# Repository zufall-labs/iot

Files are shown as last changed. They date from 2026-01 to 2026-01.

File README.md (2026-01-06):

# IoT

🤖 Everything IoT in regards to Zufall Labs hardware products

# IoT Entropy-as-a-Service

Hardware and software for generating and distributing true random numbers from chaotic oscillators.

## Architecture

- **Hardware**: Chaos Circuits Board with 4 oscillators + Raspberry Pi 4 + ADC
- **Firmware**: N/A (using Raspberry Pi OS)
- **Software**: Python-based entropy generation and MQTT publishing
- **Backend**: Service mesh for distribution (separate repos)

## Quick Start

### Hardware Setup

1. Connect Waveshare AD HAT to Raspberry Pi
2. Connect chaos circuit VCE1 → ADC IN3
3. Power: Pi 5V → Board VIN5V

### Software Setup
```bash
cd software/adapters/adc-adapters/waveshare-ads1263
pip install numpy scipy paho-mqtt

# Run diagnostics
cd ../../tools/diagnostics
sudo python3 chaos_diagnostic.py
```

## Repository Structure
```
/
├── .github/                      # GitHub specific configurations
│   ├── workflows/                # GitHub Actions CI/CD pipelines
│   ├── ISSUE_TEMPLATE/          # Issue templates
│   └── PULL_REQUEST_TEMPLATE/   # PR templates
│
├── hardware/                     # All hardware-related files
│   ├── mechanical/              # 3D designs and mechanical components
│   │   ├── cad/                 # CAD files (Fusion 360, SolidWorks, etc.)
│   │   ├── stl/                 # 3D printable files
│   │   └── drawings/            # Technical drawings and dimensions
│   │
│   ├── electronics/             # Electronic design files
│   │   ├── kicad/              # KiCad project files
│   │   │   ├── lib/            # Custom component libraries
│   │   │   ├── fp-lib-table    # Footprint library configurations
│   │   │   └── sym-lib-table   # Symbol library configurations
│   │   ├── datasheets/         # Component datasheets
│   │   └── production/         # Gerber files, BOM, assembly instructions
│   │
│   └── interfaces/             # Hardware interface specifications
│       ├── connectors/         # Connector pinouts and specifications
│       └── protocols/          # Communication protocol specifications
│
├── firmware/                    # Device firmware
│   ├── bootloader/             # Bootloader source code
│   ├── main/                   # Main firmware source code
│   ├── libs/                   # Shared firmware libraries
│   └── tools/                  # Firmware-specific tools
│
├── software/                   # Software components
│   ├── core/                   # Core business logic
│   ├── adapters/              # Hardware abstraction layers
│   │   ├── sensor-adapters/   # Different sensor implementations
│   │   └── comm-adapters/     # Communication protocol adapters
│   ├── api/                   # API definitions and implementations
│   ├── web/                   # Web applications
│   ├── mobile/                # Mobile applications
│   └── tools/                 # Development and debugging tools
│
├── tests/                      # Test suites
│   ├── hardware/              # Hardware test specifications
│   ├── firmware/              # Firmware test suites
│   └── software/              # Software test suites
│
├── docs/                       # Documentation
│   ├── architecture/          # System architecture documents
│   ├── hardware/              # Hardware documentation
│   ├── firmware/              # Firmware documentation
│   ├── software/              # Software documentation
│   ├── api/                   # API documentation
│   └── user/                  # End-user documentation
│
├── tools/                      # Development and build tools
│   ├── build-scripts/         # Build automation scripts
│   ├── ci-scripts/            # CI/CD helper scripts
│   └── dev-tools/             # Development utilities
│
├── config/                     # Configuration files
│   ├── dev/                   # Development environment configs
│   ├── prod/                  # Production environment configs
│   └── test/                  # Test environment configs
│
├── .gitignore                 # Git ignore rules
├── .editorconfig              # Editor configuration
├── LICENSE                    # Project license
├── README.md                  # Project overview and setup instructions
└── CONTRIBUTING.md            # Contribution guidelines
```

## Current Status

✅ Hardware: Chaos Circuits Board designed and tested
✅ Software: Chaos diagnostic tool working (Score: 90+)
🚧 Next: MQTT integration for entropy publishing

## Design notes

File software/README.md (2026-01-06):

# IoT Software Components

## Structure

- **adapters/**: Hardware abstraction layers
  - `adc-adapters/waveshare-ads1263/`: Driver for Waveshare High-Precision AD HAT
  
- **core/**: Core business logic
  - `entropy-generator/`: Chaos-based entropy generation
  - `mqtt-publisher/`: MQTT publishing logic
  
- **tools/**: Development and debugging tools
  - `diagnostics/`: Chaos diagnostic tool

## Setup
```bash
pip install numpy scipy paho-mqtt
```

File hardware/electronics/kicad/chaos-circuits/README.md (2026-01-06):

# Chaos Circuits Board

4 chaotic oscillator circuits on one board:
1. Chua's Circuit
2. Lorenz Attractor
3. Rössler Attractor  
4. Two-Transistor RC Oscillator

## Files

- `Chaos Circuits.kicad_pcb`: PCB layout
- `Chaos Circuits.kicad_sch`: Schematic
- `Chaos Circuits.kicad_pro`: KiCad project

## Production Files

See `/hardware/electronics/production/chaos-circuits/`

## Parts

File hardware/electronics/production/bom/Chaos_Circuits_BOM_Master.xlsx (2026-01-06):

Item # | *Designator | *Qty | Manufacturer | *Mfg Part # | Description / Value | *Package/Footprint | Type | Your Instructions / Notes
1 | C1,C2,C3,C4,C5 | 5 | Murata | GCM31CD71H106KE36K | 10 µF ±10% 50V Ceramic Capacitor X7T 1206 (3216 Metric) | 1206 | SMT
2 | C6,C12,C13,C18 | 4 | Kemet | C0805C104J5RAC7800 | 0.1 µF ±5% 50V Ceramic Capacitor X7R 0805 (2012 Metric) | 0805 | SMT
3 | C7 | 1 | Kemet | C0805C103F5GAC7800 | 10000 pF ±1% 50V Ceramic Capacitor C0G, NP0 0805 (2012 Metric) | 0805 | SMT
4 | C8,C9,C10,C11,C14,C15,C16,C17,C19,C20,C21,C22,C23,C24,C30,C31,C33,C34,C35,C36,C37,C38,C39,C40,C41,C42,C44,C45,C46,C47,C48,C49 | 32 | Samsung Electro-Mechanics | CL21B105KBFNNNE | 1 µF ±10% 50V Ceramic Capacitor X7R 0805 (2012 Metric) | 0805 | SMT
5 | C25,C26,C27 | 3 | KEMET | C0805C102J5GAC7800 | 1000 pF ±5% 50V Ceramic Capacitor C0G, NP0 0805 (2012 Metric) | 0805 | SMT
6 | C28 | 1 | YAGEO | CC0805JRNPO9BN361 | 360 pF ±5% 50V Ceramic Capacitor C0G, NP0 0805 (2012 Metric) | 0805 | SMT
7 | C29,C32,C43 | 3 | Samsung Electro-Mechanics | CL21B222JBANNNC | 2200 pF ±5% 50V Ceramic Capacitor X7R 0805 (2012 Metric) | 0805 | SMT
8 | D1,D2 | 2 | Littelfuse Inc. | SMBJ18CA | 24.4V Clamp 24.6A Ipp Tvs Diode Surface Mount DO-214AA (SMBJ) | SMB | SMT
9 | D3,D4 | 2 | STMicroelectronics | STPS2H100A | Diode 100 V 2A Surface Mount SMA (DO-214AC) | SMA | SMT
10 | D5,D6,D8 | 3 | Kingbright | APT3216LZGCK | Green 525nm LED Indication - Discrete 2.65V 1206 | 1206 | SMT
11 | J1 | 1 | Phoenix Contact | 1729131 | PCB terminal block, nominal current: 13.5 A, rated voltage (III/2): 400 V, | Connector | TH
12 | J2 | 1 | TE Connectivity AMP Connectors | 796681-2 | 2 Position Wire to Board Terminal Block Horizontal with Board 0.197" (5.00mm) Through Hole | Connector | TH
13 | L1 | 1 | Bourns Inc. | RL181S-183J-RC | 18 mH Shielded Drum Core, Wirewound Inductor 21 mA 17Ohm Max Radial, Vertical Cylinder | Radial, Vertical Cylinder | TH
14 | Q1,Q2 | 2 | onsemi | BC547CTA | Bipolar (BJT) Transistor NPN 45 V 100 mA 300MHz 500 mW Through Hole TO-92-3 | TO-92-3 | TH
15 | R1,R2,R3 | 3 | YAGEO | RC0603FR-074K7L | RES 4.7K OHM 1% 1/10W 0603 | 0603 | SMT
16 | R4 | 1 | Bourns Inc. | 3310Y-001-202L | 2k Ohm 1 Gang Linear Panel Mount Potentiometer None 1.0 Kierros Conductive Plastic 0.25W, 1/4W PC Pins | Pot | TH
17 | R5 | 1 | Stackpole Electronics Inc | RMCF1206ZT0R00 | RES 0 OHM JUMPER 1/4W 1206 | 1206 | SMT
18 | R7,R11 | 2 | Vishay Dale | CRCW080522K0FKEAC | RES 22K OHM 1% 1/8W 0805 | 0805 | SMT
19 | R8 | 1 | Vishay Dale | CRCW08053K30FKEAC | RES 3.3K OHM 1% 1/8W 0805 | 0805 | SMT
20 | R9 | 1 | TE Connectivity Passive Product | CRG0805F2K2 | RES SMD 2.2K OHM 1% 1/8W 0805 | 0805 | SMT
21 | R10,R13 | 2 | TE Connectivity Passive Product | CRG0805F220R | RES SMD 220 OHM 1% 1/8W 0805 | 0805 | SMT
22 | R12,R19,R28,R29,R32 | 5 | Panasonic Electronic Components | ERA-6AEB104V | RES SMD 100K OHM 0.1% 1/8W 0805 | 0805 | SMT
23 | R14 | 1 | Panasonic Electronic Components | ERA-6AEB3572V | RES SMD 35.7K OHM 0.1% 1/8W 0805 | 0805 | SMT
24 | R15,R17,R22,R23,R30,R31,R34,R35,R36,R38,R42,R43,R44,R45,R46 | 15 | Susumu | RG2012P-103-B-T5 | RES SMD 10K OHM 0.1% 1/8W 0805 | 0805 | SMT
25 | R16 | 1 | YAGEO | RT0805BRD071ML | RES SMD 1M OHM 0.1% 1/8W 0805 | 0805 | SMT
26 | R18 | 1 | YAGEO | YAGEO | RES SMD 374K OHM 0.1% 1/8W 0805 | 0805 | SMT
27 | R20,R21,R39 | 3 | YAGEO | RC0805FR-075K1L | RES 5.1K OHM 1% 1/8W 0805 | 0805 | SMT
28 | R24 | 1 | TE Connectivity Passive Product | CRG0805F30K | RES SMD 30K OHM 1% 1/8W 0805 | 0805 | SMT
29 | R25,R41 | 2 | Bourns Inc. | 3310Y-001-104L | 100k Ohm 1 Gang Linear Panel Mount Potentiometer None 1.0 Kierros Conductive Plastic 0.25W, 1/4W PC Pins | Pot | TH
30 | R27 | 1 | TE Connectivity Passive Product | CRG0805F15K | RES SMD 15K OHM 1% 1/8W 0805 | 0805 | SMT
31 | R33 | 1 | YAGEO | RC0805FR-07560KL | RES SMD 100K OHM 0.1% 1/8W 0805 | 0805 | SMT
32 | R37 | 1 | YAGEO | RC0805FR-0756KL | RES 56K OHM 1% 1/8W 0805 | 0805 | SMT
33 | R40 | 1 | Panasonic Electronic Components | ERJ-6ENF3903V | RES SMD 390K OHM 1% 1/8W 0805 | 0805 | SMT
34 | R47,R48,R49,R50 | 4 | YAGEO | RC0805FR-07470RL | RES 470 OHM 1% 1/8W 0805 | 0805 | SMT
35 | U1,U2,U3,U4,U5,U8,U9,U10,U11,U12,U14,U15,U16 | 13 | Texas Instruments | TL081HIDR | J-FET Amplifier 1 Circuit Push-Pull 8-SOIC | 8-SOIC | SMT
36 | U6,U7,U13 | 3 | Analog Devices Inc. | AD633JRZ-R7 | Analog Multiplier 4-Quadrant 8-SOIC | 8-SOIC | SMT

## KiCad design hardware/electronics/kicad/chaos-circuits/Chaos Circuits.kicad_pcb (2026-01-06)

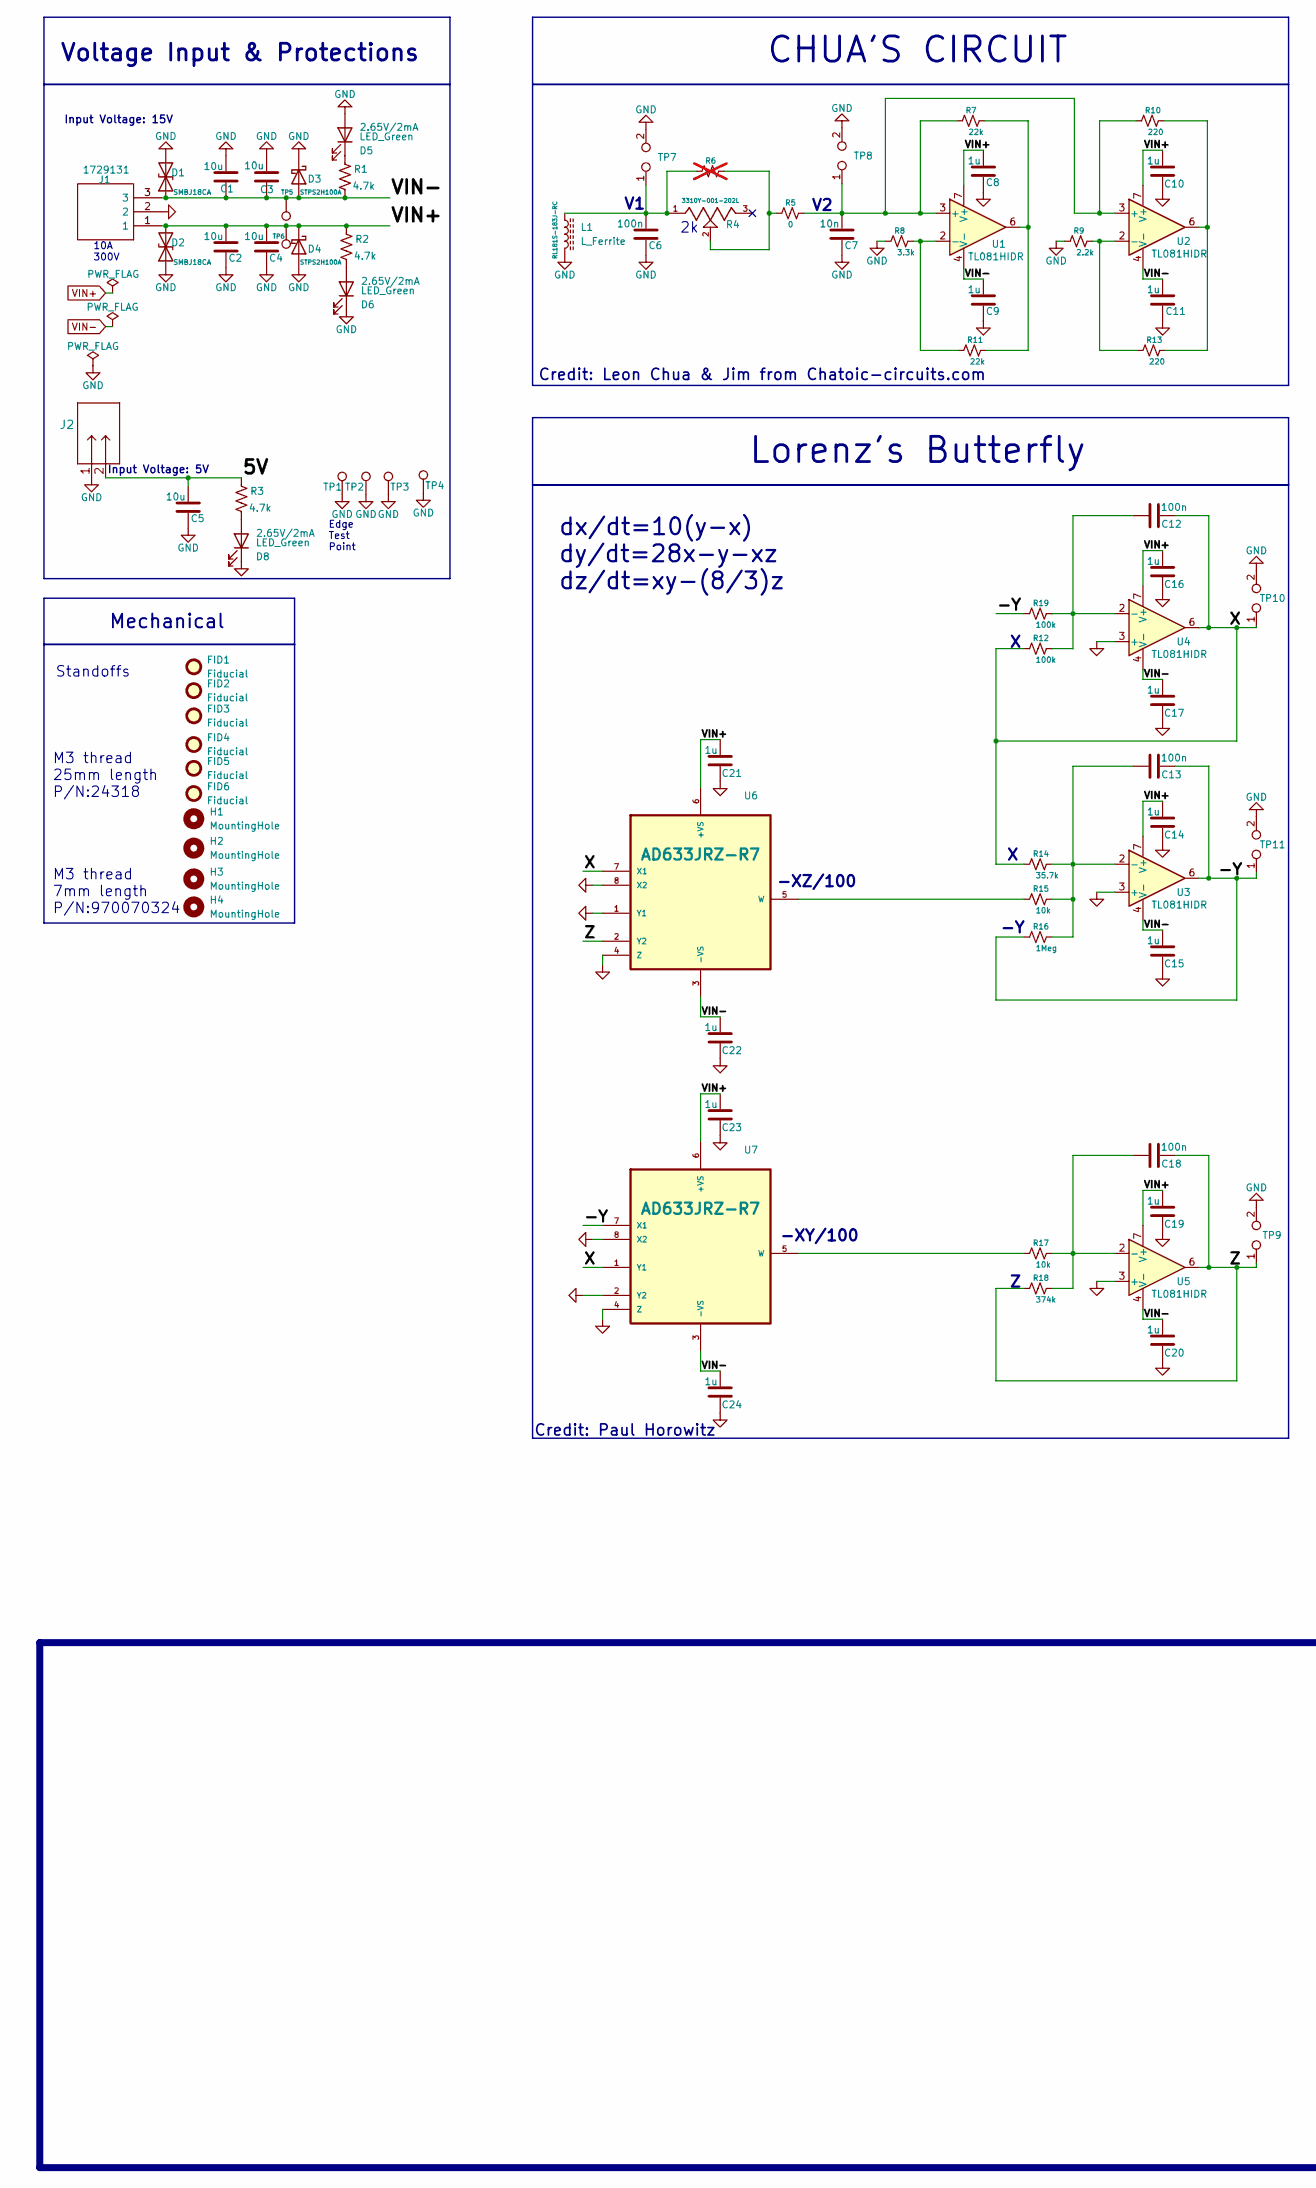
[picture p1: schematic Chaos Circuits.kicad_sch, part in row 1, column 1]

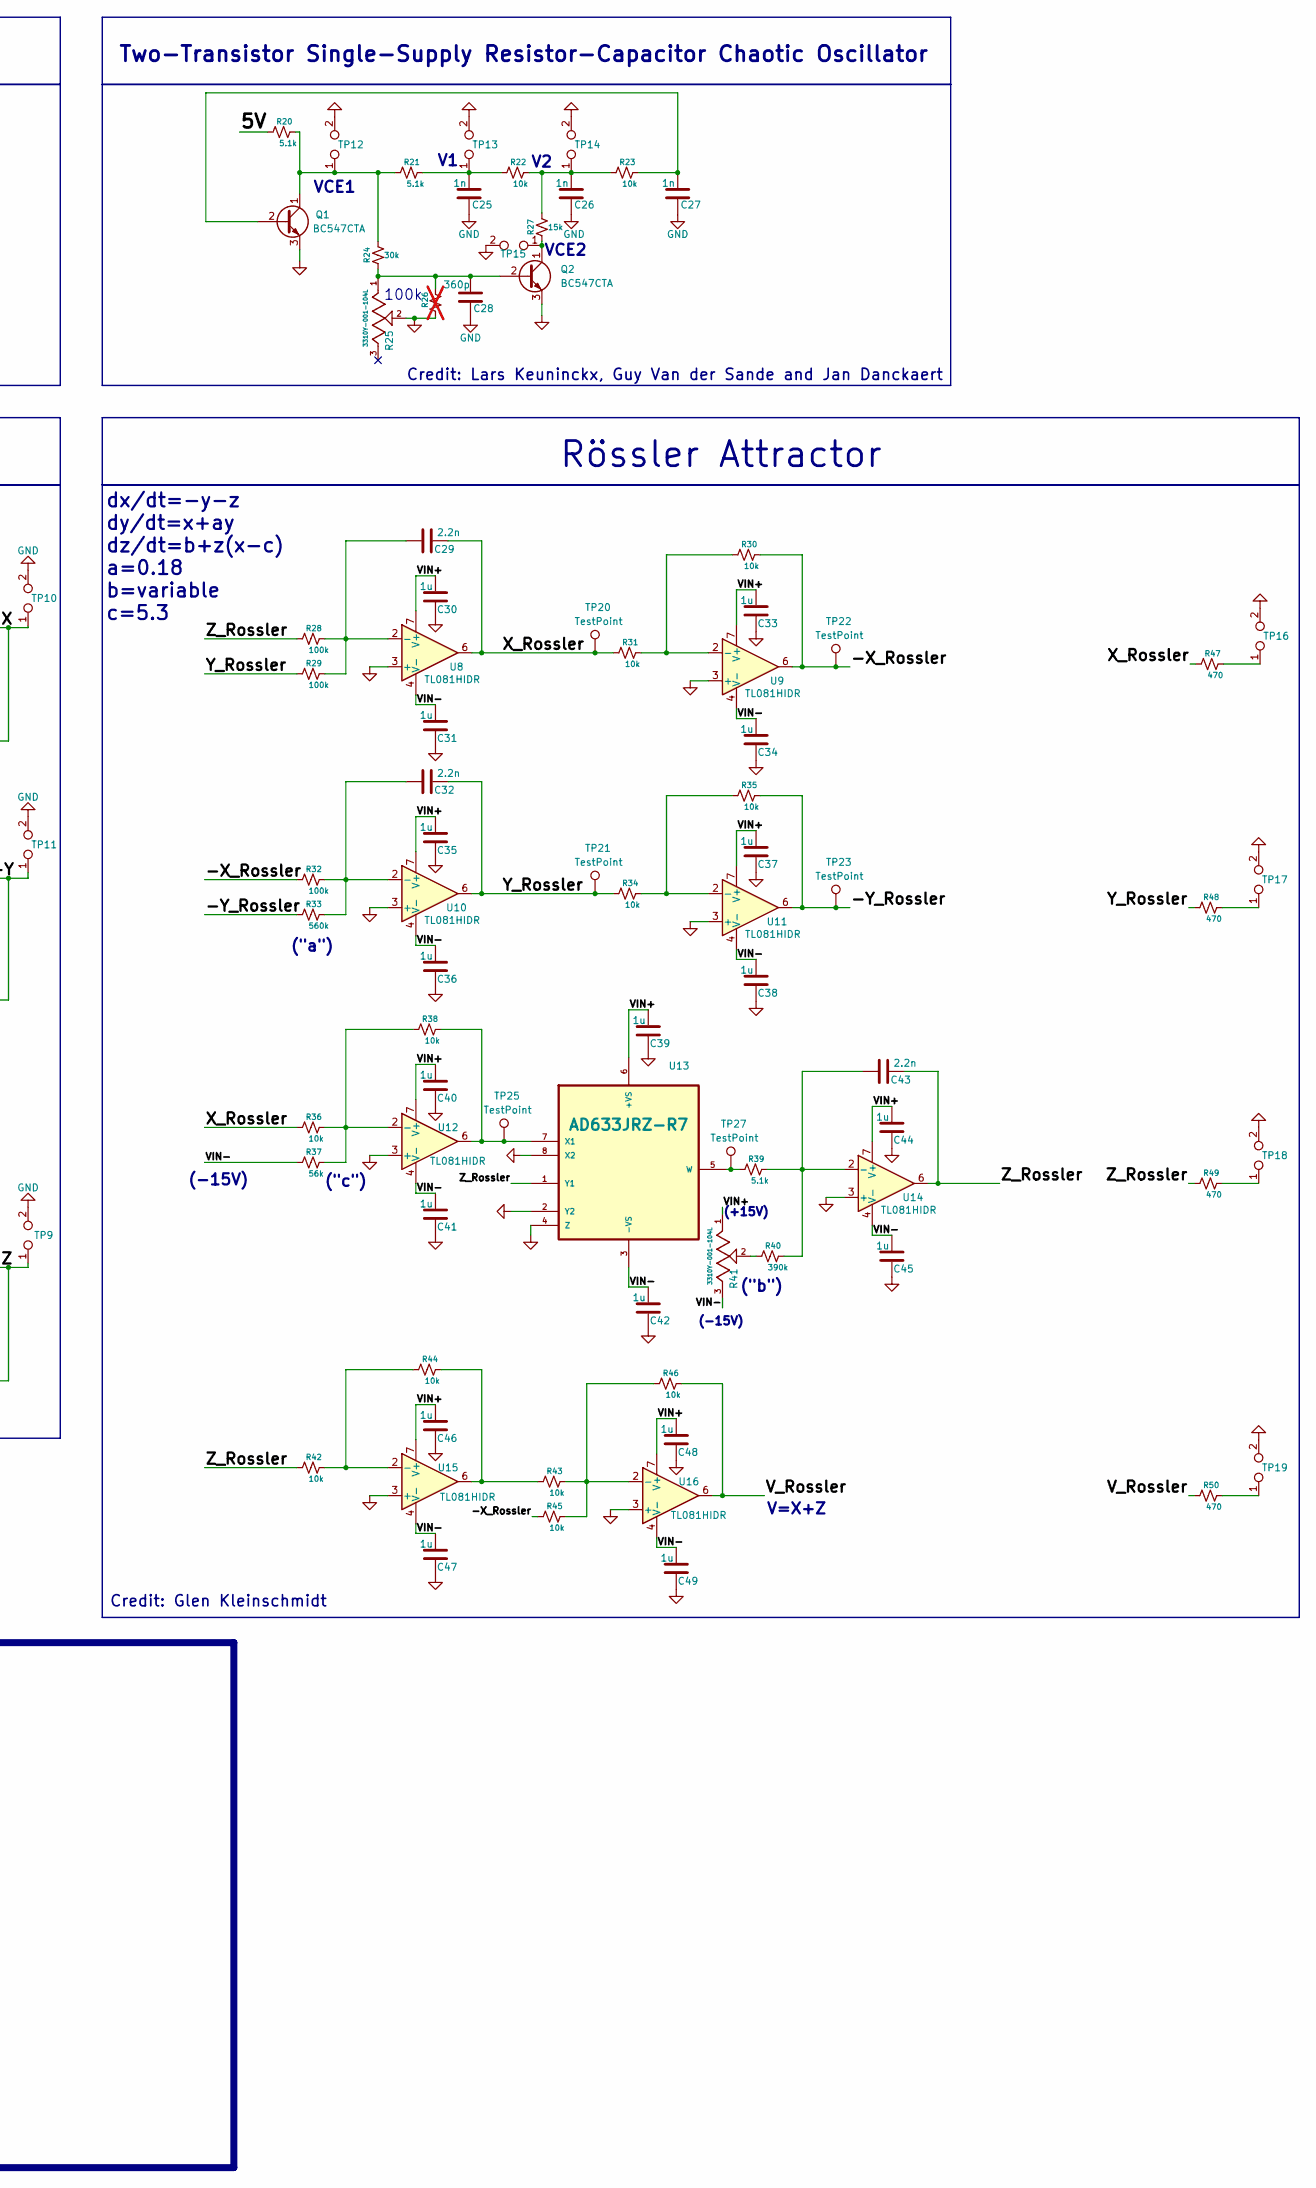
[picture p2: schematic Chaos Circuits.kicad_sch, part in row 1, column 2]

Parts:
C1, C2, C3, C4, C5: 10u; C_1206_3216Metric; Tolerance 10%; Voltage Rating 50V; Part Number GCM31CD71H106KE36K
C6, C12, C13, C18: 100n; C_0805_2012Metric; Tolerance 5%; Voltage Rating 50V; Part Number C0805C104J5RAC7800
C7: 10n; C_0805_2012Metric; Tolerance 1%; Voltage Rating 50V; Part Number C0805C103F5GAC7800
C8, C9, C10, C11, C14, C15, C16, C17, C19, C20, C21, C22, C23, C24, C30, C31, C33, C34, C35, C36, C37, C38, C39, C40, C41, C42, C44, C45, C46, C47, C48, C49: 1u; C_0805_2012Metric; Tolerance 10%; Voltage Rating 50V; Part Number CL21B105KBFNNNE
C25, C26, C27: 1n; C_0805_2012Metric; Tolerance 5%; Voltage Rating 50V; Part Number C0805C102J5GAC7800
C28: 360p; C_0805_2012Metric; Tolerance 5%; Voltage Rating 50V; Part Number CC0805JRNPO9BN361
C29, C32, C43: 2.2n; C_0805_2012Metric; Tolerance 5%; Voltage Rating 50V; Part Number CL21B222JBANNNC
D1, D2: SMBJ18CA; D_SMB; Part Number SMBJ18CA
D3, D4: STPS2H100A; SMA_STM; Voltage Rating 100V 2A; Part Number STPS2H100A
D5, D6, D8: LED_Green; LED_1206_3216Metric_Pad1.42x1.75mm_HandSolder; Voltage Rating 2.65V/2mA; Part Number APT3216LZGCK
FID1, FID2, FID3, FID4, FID5, FID6: Fiducial; Fiducial_1mm_Mask2mm
H1, H2, H3, H4: MountingHole; MountingHole_3.5mm_Pad_TopBottom
J1: 1729131; Manufacturer_Part_Number 1729131; Mouser Part Number 651-1729131
J2: 796681-2; 796681-2_TEC; Part Number 796681-2
L1: L_Ferrite; L_Radial_D10.5mm_P5.00mm_Abacron_AISR-01; Power Rating 21mA; Part Number RL181S-183J-RC
Q1, Q2: BC547CTA; TO-92_Inline; Part Number BC547CTA
R1, R2, R3: 4.7k; R_0603_1608Metric; Power Rating 0.1W; Tolerance 1%; Part Number RC0603FR-074K7L
R4: 3310Y-001-202L; TRIM_3310Y-001-202L; Power Rating 0.25W; Part Number 3310Y-001-202L
R5: 0; R_1206_3216Metric; Power Rating 1/4W; Part Number RMCF1206ZT0R00
R6, R26: 0; R_1206_3216Metric; Power Rating 1/4W; Part Number RMCF1206ZT0R00; not fitted
R7, R11: 22k; R_0805_2012Metric; Power Rating 1/8W; Tolerance 1%; Part Number CRCW080522K0FKEAC
R8: 3.3k; R_0805_2012Metric; Power Rating 1/8W; Tolerance 1%; Part Number CRCW08053K30FKEAC
R9: 2.2k; R_0805_2012Metric; Power Rating 1/8W; Tolerance 1%; Part Number CRG0805F2K2
R10, R13: 220; R_0805_2012Metric; Power Rating 1/8W; Tolerance 1%; Part Number CRG0805F220R
R12, R19, R28, R29, R32: 100k; R_0805_2012Metric; Power Rating 1/8W; Tolerance 0.1%; Part Number ERA-6AEB104V
R14: 35.7k; R_0805_2012Metric; Power Rating 1/8W; Tolerance 0.1%; Part Number ERA-6AEB3572V
R15, R17, R22, R23, R30, R31, R34, R35, R36, R38, R42, R43, R44, R45, R46: 10k; R_0805_2012Metric; Power Rating 1/8W; Tolerance 0.1%; Part Number RG2012P-103-B-T5
R16: 1Meg; R_0805_2012Metric; Power Rating 1/8W; Tolerance 0.1%; Part Number RT0805BRD071ML
R18: 374k; R_0805_2012Metric; Power Rating 1/8W; Tolerance 0.1%; Part Number YAGEO
R20, R21, R39: 5.1k; R_0805_2012Metric; Power Rating 1/8W; Tolerance 1%; Part Number RC0805FR-075K1L
R24: 30k; R_0805_2012Metric; Power Rating 1/8W; Tolerance 1%; Part Number CRG0805F30K
R25, R41: 3310Y-001-104L; TRIM_3310Y-001-202L; Power Rating 0.25W; Part Number 3310Y-001-104L
R27: 15k; R_0805_2012Metric; Power Rating 1/8W; Tolerance 1%; Part Number CRG0805F15K
R33: 560k; R_0805_2012Metric; Power Rating 1/8W; Tolerance 1%; Part Number RC0805FR-07560KL
R37: 56k; R_0805_2012Metric; Power Rating 1/8W; Tolerance 1%; Part Number RC0805FR-0756KL
R40: 390k; R_0805_2012Metric; Power Rating 1/8W; Tolerance 1%; Part Number ERJ-6ENF3903V
R47, R48, R49, R50: 470; R_0805_2012Metric; Power Rating 1/8W; Tolerance 1%; Part Number RC0805FR-07470RL
TP1: TestPoint; TestPoint_THTPad_D3.0mm_Drill1.5mm
TP2, TP3, TP4, TP5, TP6: TestPoint; TestPoint_THTPad_D2.0mm_Drill1.0mm
TP7, TP8, TP9, TP10, TP11, TP12, TP13, TP14, TP15, TP16, TP17, TP18, TP19: TestPoint_2Pole; TestPoint_Bridge_Pitch7.62mm_Drill1.3mm
TP20, TP21, TP22, TP23, TP25, TP27: TestPoint; TestPoint_Keystone_5005-5009_Compact; Part Number 5005
U1, U2, U3, U4, U5, U8, U9, U10, U11, U12, U14, U15, U16: TL081HIDR; SOIC8_D_TEX; Part Number TL081HIDR
U6, U7, U13: AD633JRZ-R7; AD633; Part Number AD633JRZ-R7

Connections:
/5V: C5.1, J2.2, R3.1, R20.1
/-X_Rossler: R30.2, R32.1, R45.1, TP22.1, U9.6
/-Y: C13.2, R16.1, R19.1, TP11.1, U3.6, U7.7 (X1)
/-Y_Rossler: R33.1, R35.2, TP23.1, U11.6
/V_Rossler: R46.2, R50.1, U16.6
/X: C12.2, R12.1, R14.1, TP10.1, U4.6, U6.7 (X1), U7.1 (Y1)
/X_Rossler: C29.2, R31.1, R36.1, R47.1, TP20.1, U8.6
/Y_Rossler: C32.2, R29.1, R34.1, R48.1, TP21.1, U10.6
/Z: C18.2, R18.1, TP9.1, U5.6, U6.2 (Y2)
/Z_Rossler: C43.2, R28.1, R42.1, R49.1, U13.1 (Y1), U14.6
GND: C1.1, C2.2, C3.1, C4.2, C5.2, C6.2, C7.2, C8.2, C9.2, C10.2, C11.2, C14.2, C15.2, C16.2, C17.2, C19.2, C20.2, C21.2, C22.2, C23.2, C24.2, C25.2, C26.2, C27.2, C28.2, C30.2, C31.2, C33.2, C34.2, C35.2, C36.2, C37.2, C38.2, C39.2, C40.2, C41.2, C42.2, C44.2, C45.2, C46.2, C47.2, C48.2, C49.2, D1.2 (A2), D2.1 (A1), D3.1 (K), D4.2 (A), D5.2 (A), D6.1 (K), D8.1 (K), J1.2, J2.1, L1.2, Q1.3 (E), Q2.3 (E), R8.1, R9.1, R25.2, R26.1, TP1.1, TP2.1, TP3.1, TP4.1, TP7.1, TP7.2, TP8.1, TP8.2, TP9.1, TP9.2, TP10.1, TP10.2, TP11.1, TP11.2, TP12.1, TP12.2, TP13.1, TP13.2, TP14.1, TP14.2, TP15.1, TP15.2, TP16.1, TP16.2, TP17.1, TP17.2, TP18.1, TP18.2, TP19.1, TP19.2, U3.3 (+), U4.3 (+), U5.3 (+), U6.1 (Y1), U6.4 (Z), U6.8 (X2), U7.2 (Y2), U7.4 (Z), U7.8 (X2), U8.3 (+), U9.3 (+), U10.3 (+), U11.3 (+), U12.3 (+), U13.2 (Y2), U13.4 (Z), U13.8 (X2), U14.3 (+), U15.3 (+), U16.3 (+)
unnamed: C6.1, L1.1, R4.1, R6.1, TP7.1
unnamed: C25.1, R21.2, R22.1, TP13.1
unnamed: C26.1, R22.2, R23.1, R27.2, TP14.1
unnamed: D5.1 (K), R1.1
unnamed: D6.2 (A), R2.2
unnamed: D8.2 (A), R3.2
unnamed: C27.1, Q1.2 (B), R23.2
unnamed: Q1.1 (C), R20.2, R21.1, R24.2, TP12.1
unnamed: C28.1, Q2.2 (B), R24.1, R25.1, R26.2
unnamed: Q2.1 (C), R27.1, TP15.1
unnamed: R4.2, R5.1, R6.2
unnamed: R10.2, R13.2, U2.6
unnamed: R7.2, R11.2, U1.6
unnamed: R40.1, R41.2
unnamed: R43.1, R44.2, U15.6
unnamed: R47.2, TP16.1
unnamed: R48.2, TP17.1
unnamed: R49.2, TP18.1
unnamed: R50.2, TP19.1
unnamed: C7.1, R5.2, R7.1, R10.1, TP8.1, U1.3 (+), U2.3 (+)
unnamed: R8.2, R11.1, U1.2 (-)
unnamed: R9.2, R13.1, U2.2 (-)
unnamed: C13.1, R14.2, R15.2, R16.2, U3.2 (-)
unnamed: C12.1, R12.2, R19.2, U4.2 (-)
unnamed: C18.1, R17.2, R18.2, U5.2 (-)
unnamed: R15.1, U6.5 (W)
unnamed: R17.1, U7.5 (W)
unnamed: C29.1, R28.2, R29.2, U8.2 (-)
unnamed: R30.1, R31.2, U9.2 (-)
unnamed: C32.1, R32.2, R33.2, U10.2 (-)
unnamed: R34.2, R35.1, U11.2 (-)
unnamed: R36.2, R37.2, R38.1, U12.2 (-)
unnamed: R39.1, TP27.1, U13.5 (W)
unnamed: R38.2, TP25.1, U12.6, U13.7 (X1)
unnamed: C43.1, R39.2, R40.2, U14.2 (-)
unnamed: R42.2, R44.1, U15.2 (-)
unnamed: R43.2, R45.2, R46.1, U16.2 (-)
VIN+: C2.1, C4.1, C8.1, C10.1, C14.1, C16.1, C19.1, C21.1, C23.1, C30.1, C33.1, C35.1, C37.1, C39.1, C40.1, C44.1, C46.1, C48.1, D2.2 (A2), D4.1 (K), J1.1, R2.1, R41.1, TP6.1, U1.7 (V+), U2.7 (V+), U3.7 (V+), U4.7 (V+), U5.7 (V+), U6.6 (+VS), U7.6 (+VS), U8.7 (V+), U9.7 (V+), U10.7 (V+), U11.7 (V+), U12.7 (V+), U13.6 (+VS), U14.7 (V+), U15.7 (V+), U16.7 (V+)
VIN-: C1.2, C3.2, C9.1, C11.1, C15.1, C17.1, C20.1, C22.1, C24.1, C31.1, C34.1, C36.1, C38.1, C41.1, C42.1, C45.1, C47.1, C49.1, D1.1 (A1), D3.2 (A), J1.3, R1.2, R37.1, R41.3, TP5.1, U1.4 (V-), U2.4 (V-), U3.4 (V-), U4.4 (V-), U5.4 (V-), U6.3 (-VS), U7.3 (-VS), U8.4 (V-), U9.4 (V-), U10.4 (V-), U11.4 (V-), U12.4 (V-), U13.3 (-VS), U14.4 (V-), U15.4 (V-), U16.4 (V-)

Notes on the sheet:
Input Voltage: 5V
Credit: Paul Horowitz
Voltage Input & Protections
Two-Transistor Single-Supply Resistor-Capacitor Chaotic Oscillator
Rössler Attractor
10A 300V
100k
dx/dt=-y-z dy/dt=x+ay dz/dt=b+z(x-c) a=0.18 b=variable c=5.3
("b")
("c")
(-15V)
Credit: Lars Keuninckx, Guy Van der Sande and Jan Danckaert
-XY/100
VCE2
VCE1
(+15V)
Edge Test Point
Mechanical
Input Voltage: 15V
("a")
Standoffs
-XZ/100
dx/dt=10(y-x) dy/dt=28x-y-xz dz/dt=xy-(8/3)z
Credit: Leon Chua & Jim from Chatoic-circuits.com
V=X+Z
M3 thread 25mm length P/N:24318
CHUA'S CIRCUIT
Lorenz's Butterfly
M3 thread 7mm length P/N:970070324
Credit: Glen Kleinschmidt

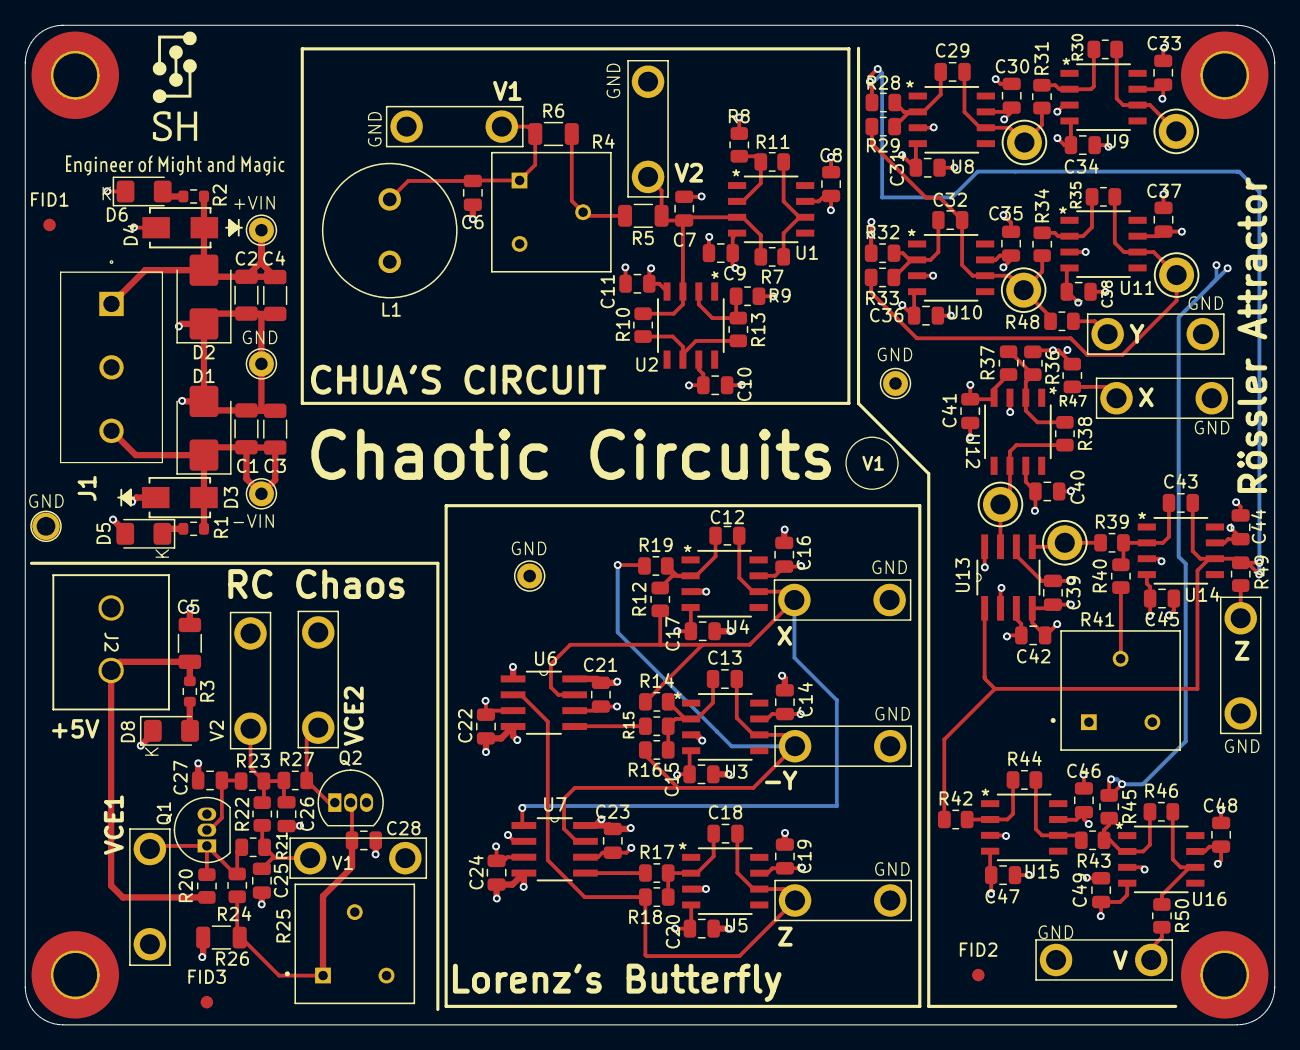
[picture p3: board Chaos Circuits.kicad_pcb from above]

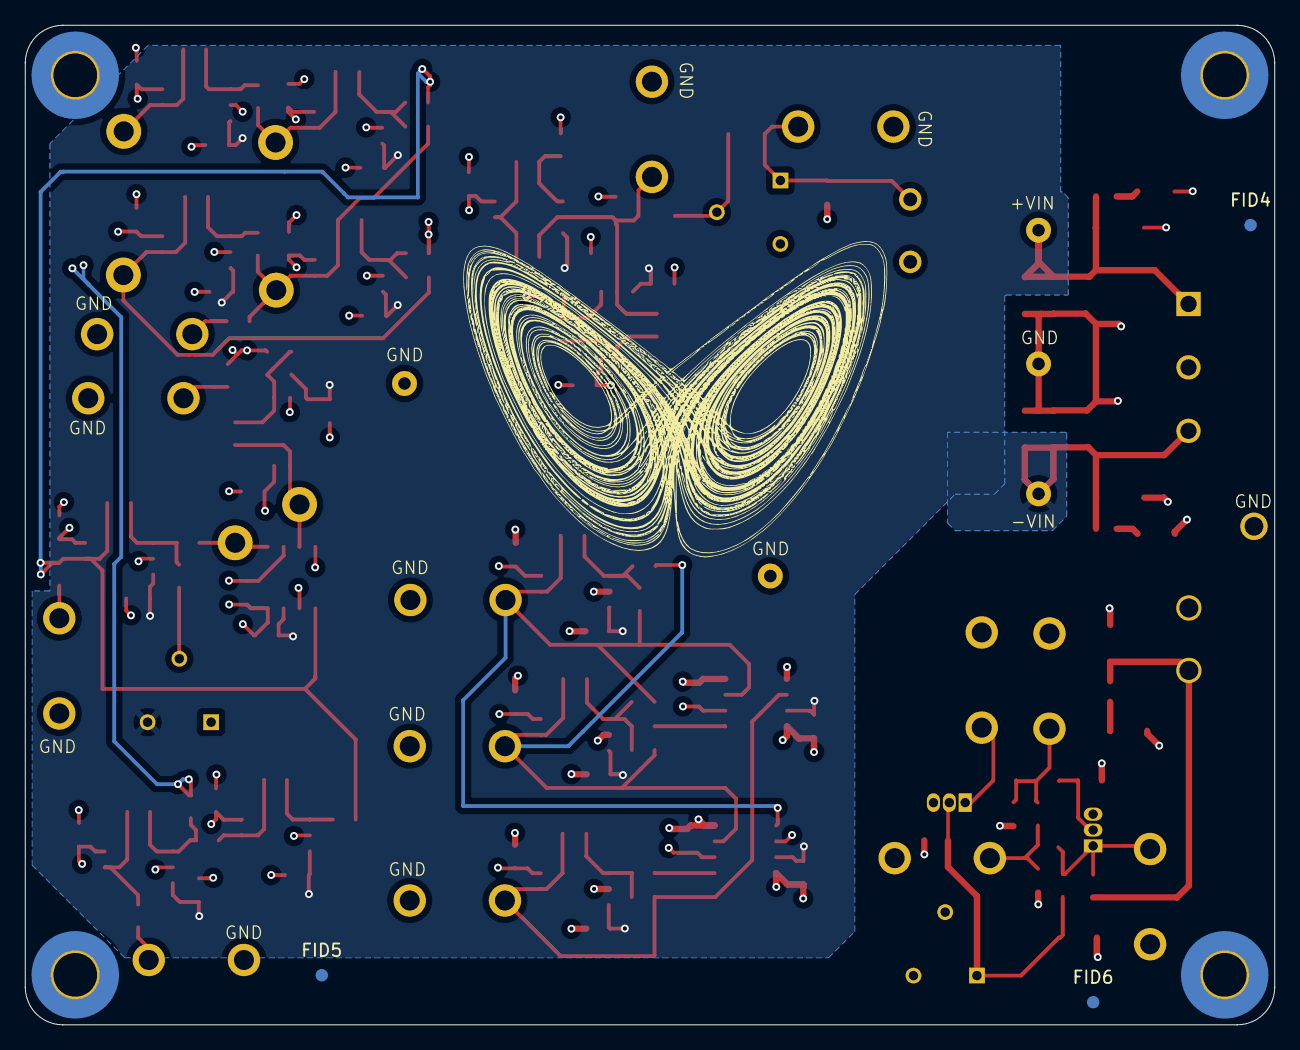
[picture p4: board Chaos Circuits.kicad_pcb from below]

Board: 4 copper layers, 100.0 x 80.0 mm, 162 parts (3 on the bottom side), 50 nets.

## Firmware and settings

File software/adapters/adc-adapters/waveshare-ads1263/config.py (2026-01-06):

# /*****************************************************************************
# * | File        :	  config.py
# * | Author      :   Waveshare team
# * | Function    :   Hardware underlying interface
# * | Info        :
# *----------------
# * | This version:   V1.0
# * | Date        :   2020-12-12
# * | Info        :   
# ******************************************************************************/
# Permission is hereby granted, free of charge, to any person obtaining a copy
# of this software and associated documnetation files (the "Software"), to deal
# in the Software without restriction, including without limitation the rights
# to use, copy, modify, merge, publish, distribute, sublicense, and/or sell
# copies of the Software, and to permit persons to  whom the Software is
# furished to do so, subject to the following conditions:
#
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
import os
import sys
import time

class RaspberryPi:
    # Pin definition
    RST_PIN     = 18
    CS_PIN      = 22
    DRDY_PIN    = 17

    def __init__(self):
    # SPI device, bus = 0, device = 0
        import spidev
        import RPi.GPIO
        
        self.GPIO = RPi.GPIO
        self.SPI = spidev.SpiDev(0, 0)

    def digital_write(self, pin, value):
        self.GPIO.output(pin, value)

    def digital_read(self, pin):
        return self.GPIO.input(pin)

    def delay_ms(self, delaytime):
        time.sleep(delaytime / 1000.0)

    def spi_writebyte(self, data):
        self.SPI.writebytes(data)
        
    def spi_readbytes(self, reg):
        return self.SPI.readbytes(reg)
        
    def module_init(self):
        self.GPIO.setmode(self.GPIO.BCM)
        self.GPIO.setwarnings(False)
        self.GPIO.setup(self.RST_PIN, self.GPIO.OUT)
        self.GPIO.setup(self.CS_PIN, self.GPIO.OUT)
        
        self.GPIO.setup(self.DRDY_PIN, self.GPIO.IN, pull_up_down=self.GPIO.PUD_UP)
        self.SPI.max_speed_hz = 2000000
        self.SPI.mode = 0b01
        return 0;

    def module_exit(self):
        self.SPI.close()
        self.GPIO.output(self.RST_PIN, 0)
        self.GPIO.output(self.CS_PIN, 0)
        self.GPIO.cleanup()
        
        
class JetsonNano:
    # Pin definition
    RST_PIN         = 18
    CS_PIN          = 22
    DRDY_PIN        = 17

    def __init__(self):
        import spidev
        self.SPI = spidev.SpiDev(0, 0)
        
        import Jetson.GPIO
        self.GPIO = Jetson.GPIO

    def digital_write(self, pin, value):
        self.GPIO.output(pin, value)

    def digital_read(self, pin):
        return self.GPIO.input(pin)

    def delay_ms(self, delaytime):
        time.sleep(delaytime / 1000.0)

    def spi_writebyte(self, data):
        self.SPI.writebytes(data)
        
    def spi_readbytes(self, reg):
        return self.SPI.readbytes(reg)

    def module_init(self):
        self.GPIO.setmode(self.GPIO.BCM)
        self.GPIO.setwarnings(False)
        self.GPIO.setup(self.RST_PIN, self.GPIO.OUT)
        self.GPIO.setup(self.CS_PIN, self.GPIO.OUT)
        self.GPIO.setup(self.DRDY_PIN, self.GPIO.IN)
        self.SPI.max_speed_hz = 2000000
        self.SPI.mode = 0b01
        return 0

    def module_exit(self):
        self.SPI.close()
        self.GPIO.output(self.RST_PIN, 0)

        self.GPIO.cleanup()
        
hostname = os.popen("uname -n").read().strip()
        
#if os.path.exists('/sys/bus/platform/drivers/gpiomem-bcm2835'):
implementation = RaspberryPi()


for func in [x for x in dir(implementation) if not x.startswith('_')]:
    setattr(sys.modules[__name__], func, getattr(implementation, func))
